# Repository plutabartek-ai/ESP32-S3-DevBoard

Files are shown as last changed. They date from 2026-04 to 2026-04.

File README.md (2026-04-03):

# ESP32-S3-DevBoard
Zadanie rekrutacyjne - projekt płytki PCB dla modułu ESP32-S3

Projekt kompletnej płytki rozwojowej opartej na układzie **ESP32-S3**, wykonany w ramach zadania rekrutacyjnego.

##  Kluczowe funkcjonalności
* **MCU:** ESP32-S3-WROOM (Wi-Fi + BLE)
* **Zasilanie i Komunikacja:** Port USB-C z układem LDO 3.3V.
* **Interakcja:** Przyciski BOOT i RESET, dioda LED statusowa.
* **Sensory:** Zintegrowany akcelerometr i żyroskop BMI270.

##  Struktura repozytorium
* `/Project_Files` - Pliki źródłowe KiCad (.kicad_sch, .kicad_pcb)
* `/Production` - Pliki Gerber i BOM przygotowane do zamówienia.
* `/step` - Model płytki w formacie .STEP.

##  Wizualizacja projektu
# Schemat ideowy Schemat
# Widok PCB PCB
# Model 3D
Model_3D_przód
Model_3D_bok

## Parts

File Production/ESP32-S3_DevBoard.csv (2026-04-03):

Reference | Qty | Value | DNP | Exclude from BOM | Exclude from Board | Footprint | Datasheet
C1,C2 | 2 | 10u |  |  |  | Capacitor_SMD:C_0603_1608Metric
D1,D2 | 2 | LED |  |  |  | LED_SMD:LED_0603_1608Metric
J1 | 1 | USB_C_Receptacle_USB2.0_16P |  |  |  | Connector_USB:USB_C_Receptacle_HRO_TYPE-C-31-M-12 | https://www.usb.org/sites/default/files/documents/usb_type-c.zip
J2,J3 | 2 | Conn_01x16_Pin |  |  |  | Connector_PinHeader_2.54mm:PinHeader_1x16_P2.54mm_Vertical
R1,R2 | 2 | 5.1k |  |  |  | Resistor_SMD:R_0603_1608Metric
R3 | 1 | 10k |  |  |  | Resistor_SMD:R_0603_1608Metric
R4,R5 | 2 | 4.7k |  |  |  | Resistor_SMD:R_0603_1608Metric
R6,R7 | 2 | 1k |  |  |  | Resistor_SMD:R_0603_1608Metric
SW1 | 1 | BOOT |  |  |  | Button_Switch_SMD:SW_Push_1TS009xxxx-xxxx-xxxx_6x6x5mm
SW2 | 1 | RESET |  |  |  | Button_Switch_SMD:SW_Push_1TS009xxxx-xxxx-xxxx_6x6x5mm
U1 | 1 | ESP32-S3-WROOM-1 |  |  |  | RF_Module:ESP32-S3-WROOM-1 | https://www.espressif.com/sites/default/files/documentation/esp32-s3-wroom-1_wroom-1u_datasheet_en.pdf
U2 | 1 | AP2112K-3.3 |  |  |  | Package_TO_SOT_SMD:SOT-23-5 | https://www.diodes.com/assets/Datasheets/AP2112.pdf
U3 | 1 | BMI270 |  |  |  | Package_LGA:Bosch_LGA-14_3x2.5mm_P0.5mm | https://www.bosch-sensortec.com/media/boschsensortec/downloads/datasheets/bst-bmi160-ds000.pdf

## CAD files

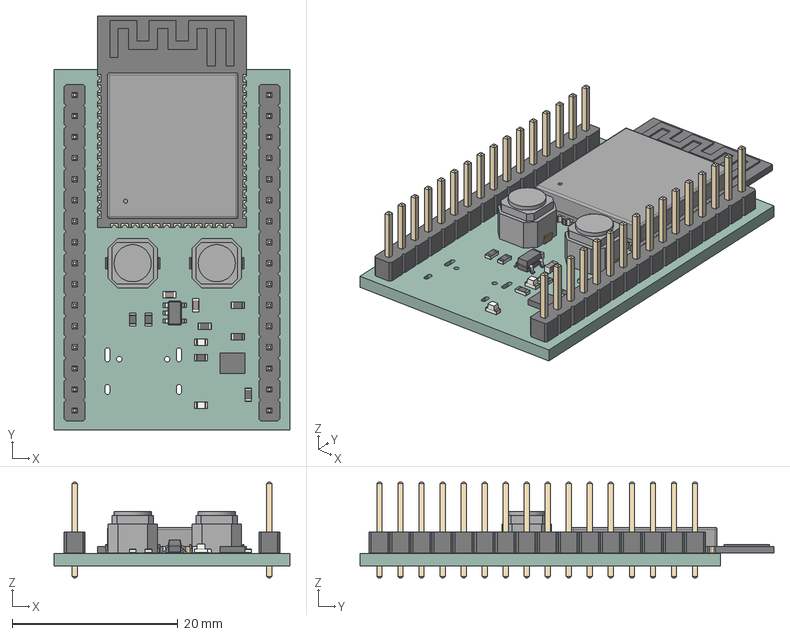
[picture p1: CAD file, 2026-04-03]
.step
28.5 x 50.0 x 11.5 mm
PinHeader_1x16_P2.54mm_Vertical x 2
pin_1 x 2
pin_2 x 2
R_0603_1608Metric x 7
C_0603_1608Metric x 2
ESP32-S3-WROOM-1
LED_0603_1608Metric x 2
SOT-23-5
Bosch_LGA-14_3x2.5mm_P0.5mm
ESP32-S3_DevBoard_PCB

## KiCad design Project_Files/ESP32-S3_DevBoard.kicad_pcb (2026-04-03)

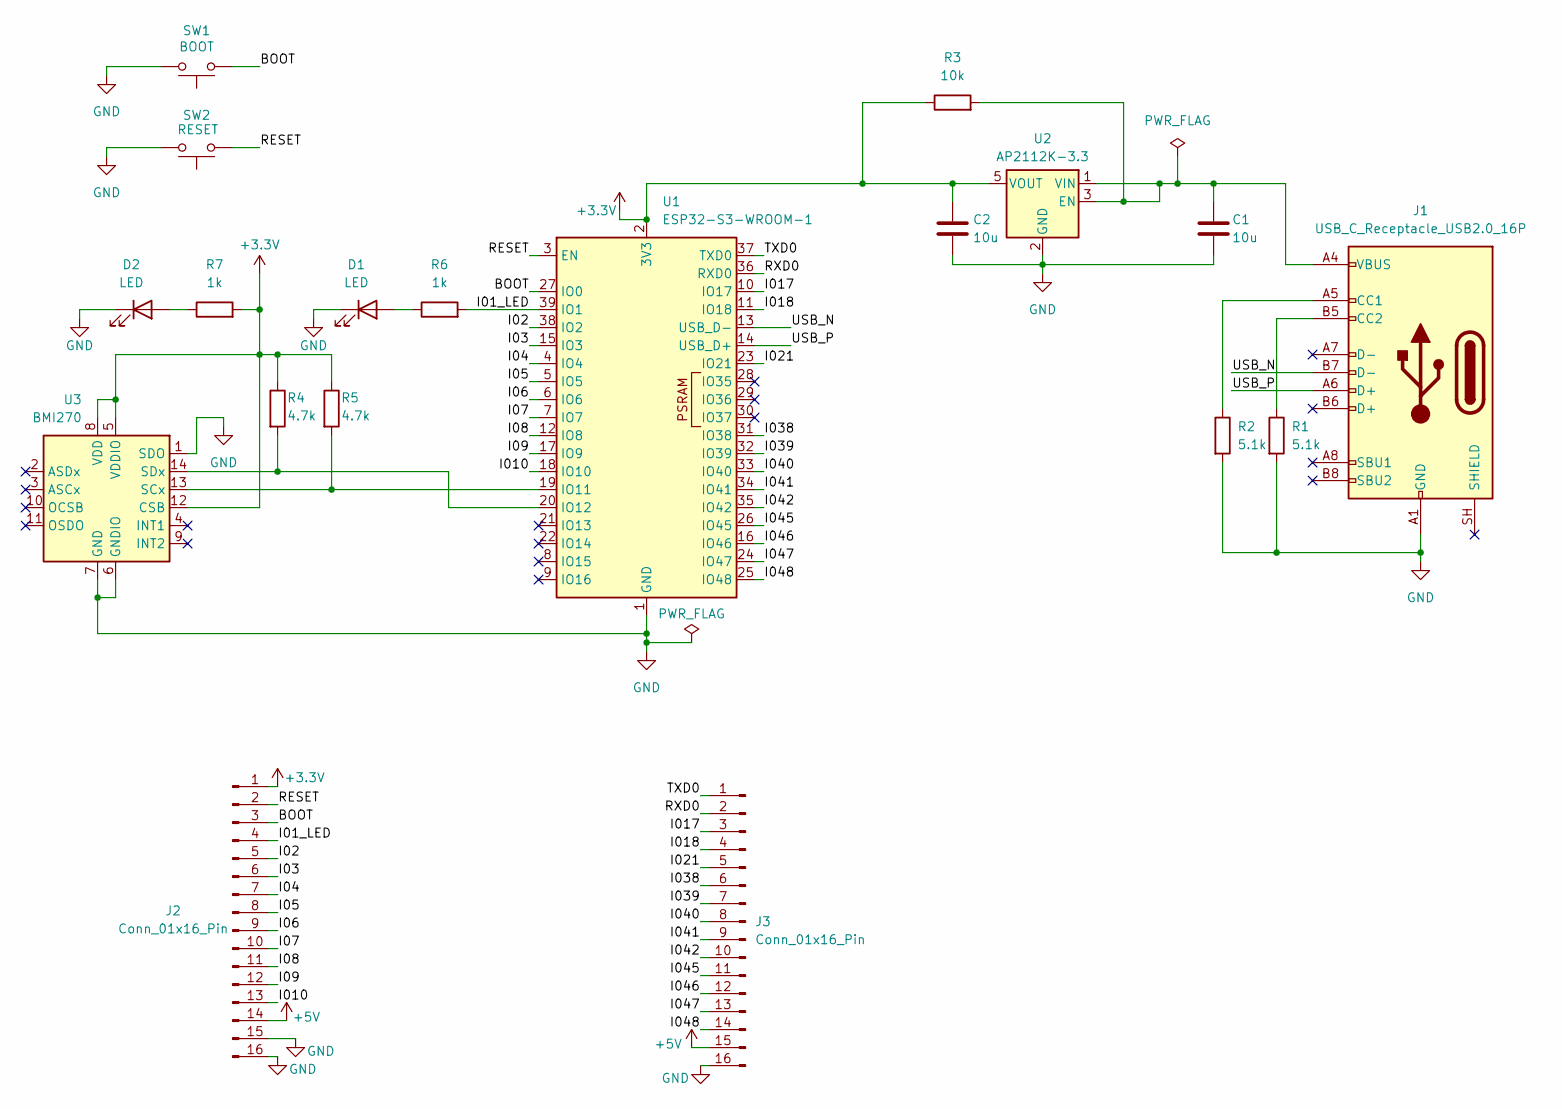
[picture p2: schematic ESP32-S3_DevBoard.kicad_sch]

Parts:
C1, C2: 10u; C_0603_1608Metric
D1, D2: LED; LED_0603_1608Metric
J1: USB_C_Receptacle_USB2.0_16P; USB_C_Receptacle_HRO_TYPE-C-31-M-12
J2, J3: Conn_01x16_Pin; PinHeader_1x16_P2.54mm_Vertical
R1, R2: 5.1k; R_0603_1608Metric
R3: 10k; R_0603_1608Metric
R4, R5: 4.7k; R_0603_1608Metric
R6, R7: 1k; R_0603_1608Metric
SW1: BOOT; SW_Push_1TS009xxxx-xxxx-xxxx_6x6x5mm
SW2: RESET; SW_Push_1TS009xxxx-xxxx-xxxx_6x6x5mm
U1: ESP32-S3-WROOM-1
U2: AP2112K-3.3; SOT-23-5
U3: BMI270; Bosch_LGA-14_3x2.5mm_P0.5mm

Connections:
+3.3V: C2.1, J2.1, R3.1, R4.1, R5.1, R7.2, U1.2 (3V3), U2.5 (VOUT), U3.5 (VDDIO), U3.8 (VDD), U3.12 (CSB)
+5V: J2.14, J3.15
/BOOT: J2.3, SW1.2, U1.27 (IO0)
/I01_LED: J2.4, R6.2, U1.39 (IO1)
/I02: J2.5, U1.38 (IO2)
/I03: J2.6, U1.15 (IO3)
/I04: J2.7, U1.4 (IO4)
/I05: J2.8, U1.5 (IO5)
/I06: J2.9, U1.6 (IO6)
/I07: J2.10, U1.7 (IO7)
/I08: J2.11, U1.12 (IO8)
/I09: J2.12, U1.17 (IO9)
/I010: J2.13, U1.18 (IO10)
/I017: J3.3, U1.10 (IO17)
/I018: J3.4, U1.11 (IO18)
/I021: J3.5, U1.23 (IO21)
/I038: J3.6, U1.31 (IO38)
/I039: J3.7, U1.32 (IO39)
/I040: J3.8, U1.33 (IO40)
/I041: J3.9, U1.34 (IO41)
/I042: J3.10, U1.35 (IO42)
/I045: J3.11, U1.26 (IO45)
/I046: J3.12, U1.16 (IO46)
/I047: J3.13, U1.24 (IO47)
/I048: J3.14, U1.25 (IO48)
/RESET: J2.2, SW2.1, U1.3 (EN)
/RXD0: J3.2, U1.36 (RXD0)
/TXD0: J3.1, U1.37 (TXD0)
/USB_N: J1.B7 (D-), U1.13 (USB_D-)
/USB_P: J1.A6 (D+), U1.14 (USB_D+)
GND: C1.2, C2.2, D1.1 (K), D2.1 (K), J1.A1 (GND), J1.A12 (GND), J1.B1 (GND), J1.B12 (GND), J2.15, J2.16, J3.16, R1.2, R2.2, SW1.1, SW2.2, U1.1 (GND), U1.40 (GND), U1.41 (GND), U2.2 (GND), U3.1 (SDO), U3.6 (GNDIO), U3.7 (GND)
unnamed: D1.2 (A), R6.1
unnamed: D2.2 (A), R7.1
unnamed: J1.A5 (CC1), R2.1
unnamed: J1.B5 (CC2), R1.1
unnamed: R5.2, U1.19 (IO11), U3.13 (SCx)
unnamed: R4.2, U1.20 (IO12), U3.14 (SDx)
unnamed: C1.1, J1.A4 (VBUS), J1.A9 (VBUS), J1.B4 (VBUS), J1.B9 (VBUS), R3.2, U2.1 (VIN), U2.3 (EN)

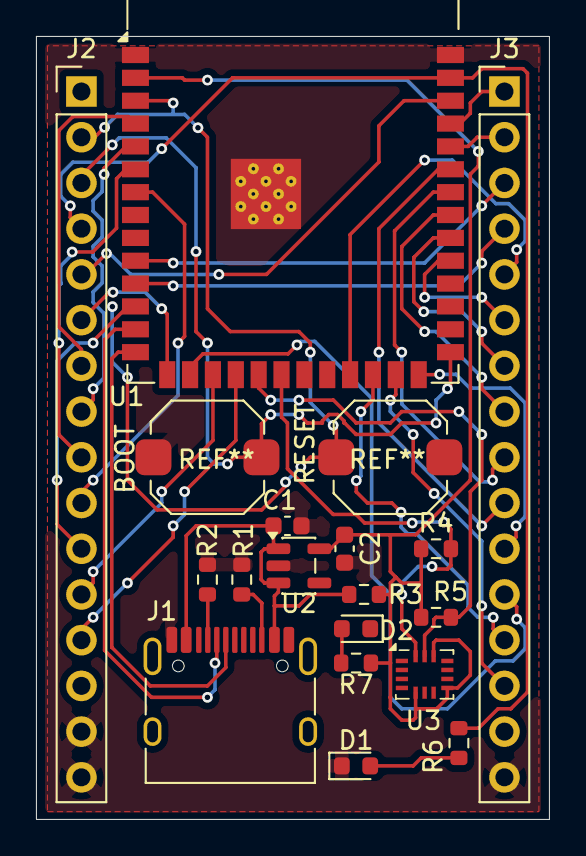
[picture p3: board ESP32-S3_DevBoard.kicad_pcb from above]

Board: 2 copper layers, 28.5 x 43.5 mm, 19 parts (0 on the bottom side), 38 nets.
